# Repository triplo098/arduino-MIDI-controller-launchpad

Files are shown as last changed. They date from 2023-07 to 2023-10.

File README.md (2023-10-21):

# Arduino MIDI Controller Project

This project is a MIDI controller, based on an Arduino Pro Micro. It can generate and send MIDI messages based on user input from potentiometers, a keypad, and various configuration parameters. In other words it is DIY launchpad! 

## Video presentation
I'm using here [BandLab](https://www.bandlab.com/feed/trending)  - easy-to-use platform for creating music.

<p align="center">
<a href="http://www.youtube.com/watch?feature=player_embedded&v=7bkNr0ojT5M
" target="_blank">IMAGE ALT TEXT HERE</a>
</p>

## Libraries Used

The following libraries are used in this project:
- [MIDIUSB](https://github.com/arduino-libraries/MIDIUSB/): This library provides MIDI functionality over USB.
- [Keypad](https://github.com/Chris--A/Keypad): This library facilitates interfacing with a keypad matrix.
- [Mux](https://github.com/stechio/arduino-ad-mux-lib): This library supports multiplexing analog inputs.
- [FastLED](https://github.com/FastLED/FastLED): This library allows control of addressable LEDs.

## Functionality

The Arduino Pro Micro MIDI controller supports the following features:

- Modes of Operation:
  - The controller supports multiple modes, such as SETUP_MODE, NORMAL_MODE, and AUTO_MODE.
  - Modes can be changed using a specific keypad sequence - hold down-left + down-rigth keys for 2 seconds.

- MIDI Note Generation in NORMAL_MODE:
  - Potentiometers are used to generate MIDI control change messages.
  - Keypad buttons trigger MIDI note on and note off events.

- Tonality, Tonic and Chord Control in SETUP_MODE:
  - The tonality and tonic note can be selected using potentiometers. The same with number of notes to play. Increasing potentiometer value equals stacking more notes on top of each other in thirds, max 4 notes which gives us 7th chords eg. c e g h -> C maj7. 
  - Different scale modes (Major, Natural Minor, Harmonic Minor, Pentatonic, Chromatic) can be chosen.

- LED Visualization:
  - LEDs are used to visualize potentiometer values and sending notes.

## Usage

1. Assemble Hardware: Wire up the potentiometers, keypad, and LEDs according to the circut schematic. Print 3D parts from launchpad_parts folder, I used black PLA for top part and lucent PETG for rest, so light from LEDs was visible. 
2. Install required libraries.
3. Connect the Arduino device using USB and upload code.
4. Have fun and be creative!

## Additional Notes
Changing code structure to OOP approach- work in progress:)

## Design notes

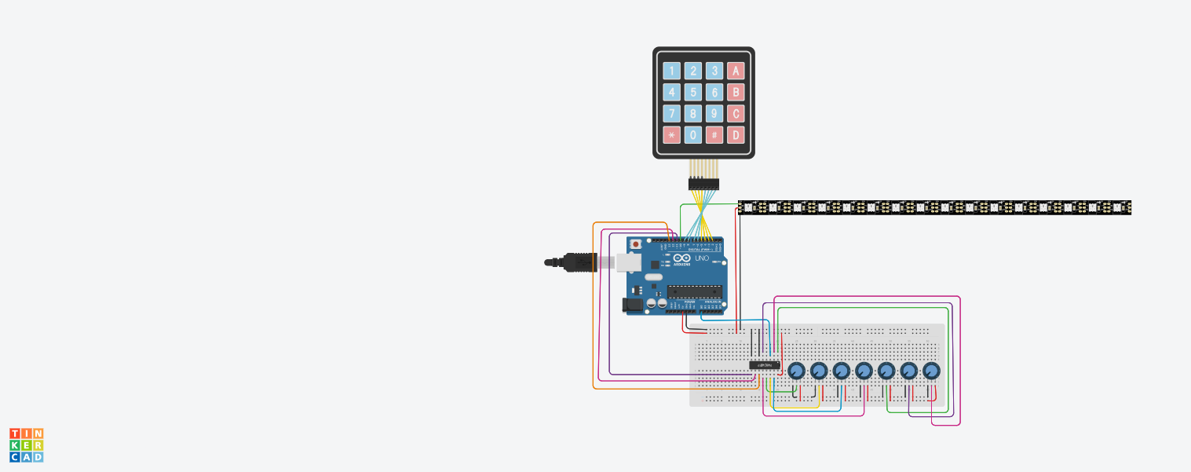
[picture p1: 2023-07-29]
launchpad_circut_schematic.png

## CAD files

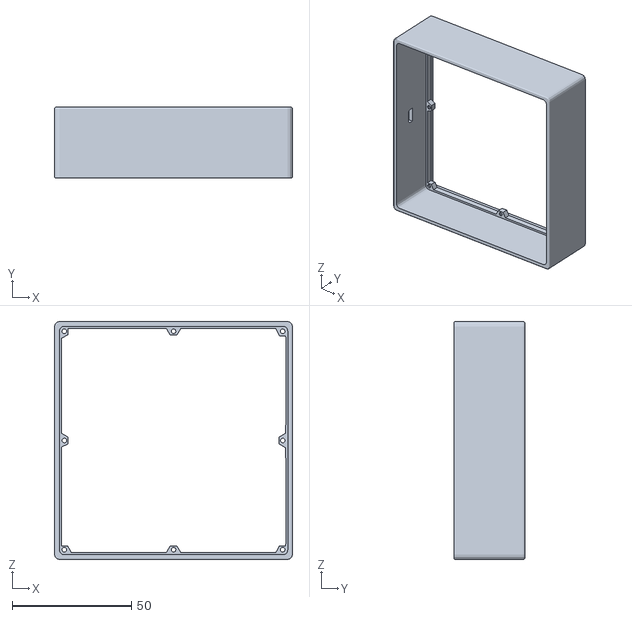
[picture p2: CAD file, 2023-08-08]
launchpad_parts/launchpad_sides.stl
100.0 x 30.0 x 100.0

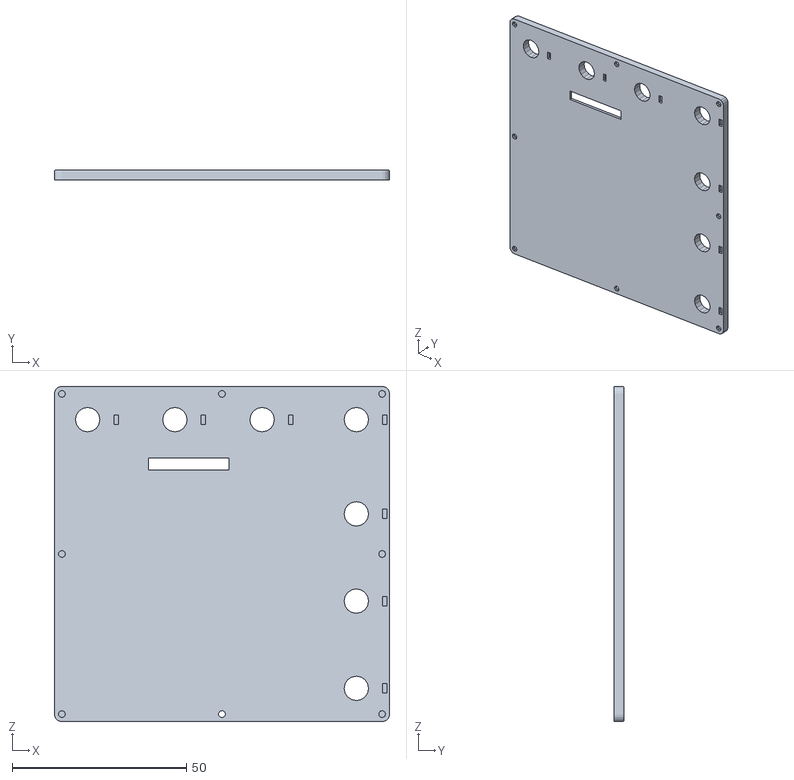
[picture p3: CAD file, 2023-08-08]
launchpad_parts/launchpad_up.stl
96.0 x 3.00 x 96.0

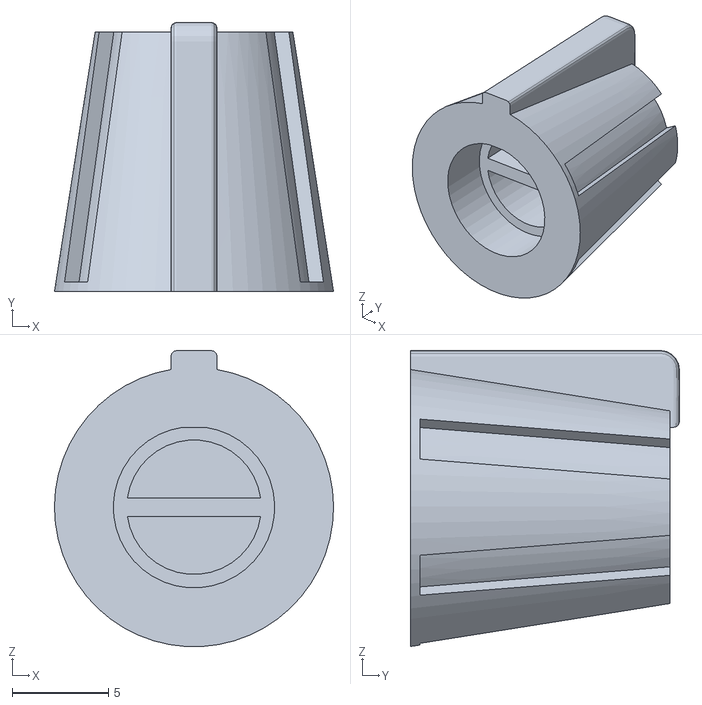
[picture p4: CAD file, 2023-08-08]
launchpad_parts/potentiometer_cap.stl
14.5 x 14.0 x 15.4

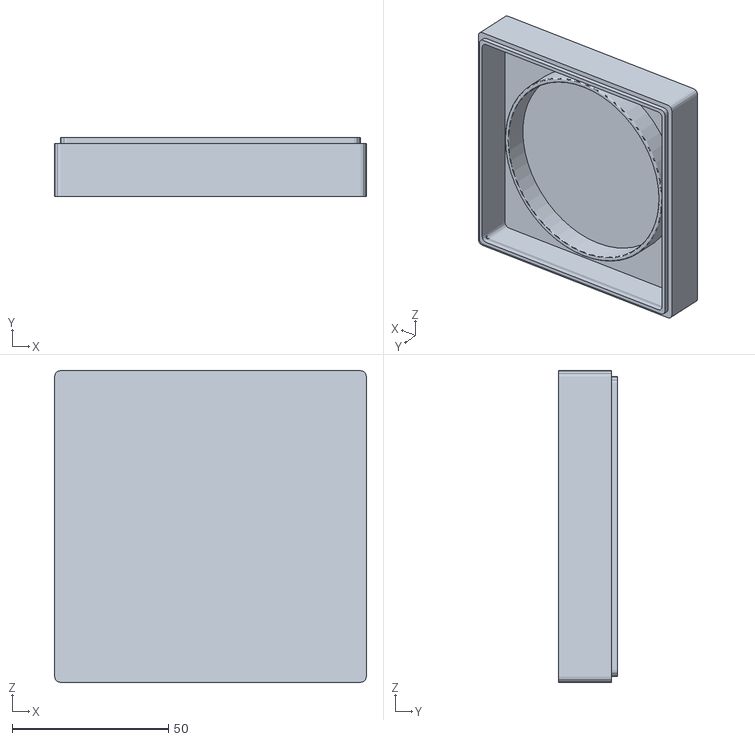
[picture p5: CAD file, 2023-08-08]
launchpad_parts/launchpad_bottom.stl
100.0 x 19.0 x 100.0

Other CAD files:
launchpad_parts/potentiometer_cap_plus_90_deg.stl

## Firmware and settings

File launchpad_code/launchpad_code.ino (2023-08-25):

#include "MIDIUSB.h"

#include <Keypad.h>

#include "Mux.h"

#include <Arduino.h>

#include <FastLED.h>


/*********************
Preparing multiplexer with potentiometers
*********************/
using namespace admux;

Mux mux(admux::Pin(A0, INPUT, PinType::Analog), Pinset(16, 15, 14));

#define NUMBER_OF_POTS 7

struct potentiometer {

  int mux_channel; 
  int control_number;
  int pre_value;
  int value;
  int channel = 0;
};

potentiometer potentiometers[NUMBER_OF_POTS];

int acceptance_rate = 16; //analong value in range betweet 0 and 1023       


/*********************
Preparing "music logic" and MIDI default parameters
*********************/
#define MAX_NOTES 12
#define MAJOR 'M'
#define MINOR_NAT 'm'
#define MINOR_HAR 'n'
#define PENTATONIC 'p'
#define CHROMATIC 'c'

byte base_velocity = 100;
byte base_channel = 0;

class scale {

  public:
  char tonality; //determine what intervals are between notes
  byte tonic;    //represents first note of scale
  byte notes[MAX_NOTES];
  byte chord_notes = 1; //number of notes stacked up while sending MIDI signal

  scale() {

    //initializing notes with error message
    for(int i = 0; i < MAX_NOTES; i++) notes[i] = 255;
    tonic = 60;
    tonality = MINOR_HAR;

    notes[0] = 0; notes[1] = 2;
    notes[2] = 4; notes[3] = 5; 
    notes[4] = 7; notes[5] = 9;
    notes[6] = 11;
  };
  
  byte count_notes() {

    byte count = 0;
    for(int i = 0; i < MAX_NOTES; i++) if(notes[i] != 255) count++;
    return count;
  }

  void set_tonic(byte tonic) {

    this -> tonic = tonic;
  }

  void set_tonality(char tonality) {

    this -> tonality = tonality;

    //error message
    for(int i = 0; i < MAX_NOTES; i++) notes[i] = 255;
    switch (tonality) {
    case 'n':
      notes[0] = 0; notes[1] = 2;
      notes[2] = 3; notes[3] = 5;
      notes[4] = 7; notes[5] = 8;
      notes[6] = 10;
      break;
    case 'm':
      notes[0] = 0; notes[1] = 2; 
      notes[2] = 3; notes[3] = 5;
      notes[4] = 7; notes[5] = 8;
      notes[6] = 11;
      break;
    case 'M':
      notes[0] = 0; notes[1] = 2;
      notes[2] = 4; notes[3] = 5; 
      notes[4] = 7; notes[5] = 9;
      notes[6] = 11;
      break;
    case 'p':
      notes[0] = 0; notes[1] = 2;
      notes[2] = 4; notes[3] = 7;
      notes[4] = 9;
      break;
    case 'c': default:
      for(int i = 0; i < MAX_NOTES; i++) notes[i] = i;      
      break;
    }    
  }
};

scale scale;


/*********************
Preparing LEDs
*********************/
#define LED_PIN 10
#define NUM_LEDS 15

int updates_per_second = 50;

CRGB leds[NUM_LEDS];

CRGBPalette16 leds_palette;
TBlendType leds_blend;

unsigned long leds_timer = 0;


/*********************
Preparing Keypad
*********************/
const byte ROWS = 4;
const byte COLS = 4;

char keys[ROWS][COLS];

byte rowPins[ROWS] = {5, 4, 3, 2};
byte colPins[COLS] = {9, 8, 7, 6}; 

Keypad kpd = Keypad( makeKeymap(keys), rowPins, colPins, ROWS, COLS );

unsigned long keys_hold_time = 0;


/*********************
Default send-MIDI functions from MIDIUSB/examples/MIDIUSB_write/MIDIUSB_write.ino
*********************/
void noteOn(byte channel, byte pitch, byte velocity) {
  midiEventPacket_t noteOn = {0x09, 0x90 | channel, pitch, velocity};
  MidiUSB.sendMIDI(noteOn);
}

void noteOff(byte channel, byte pitch, byte velocity) {
  midiEventPacket_t noteOff = {0x08, 0x80 | channel, pitch, velocity};
  MidiUSB.sendMIDI(noteOff);
}

void controlChange(byte channel, byte control, byte value) {
  midiEventPacket_t event = {0x0B, 0xB0 | channel, control, value};
  MidiUSB.sendMIDI(event);
}


#define SETUP_MODE 0
#define NORMAL_MODE 1
#define AUTO_MODE 2 //TO DO - not implemented yet

byte mode;
byte change_mode_count = 0;

void setup() {
  FastLED.addLeds<WS2812, LED_PIN, GRB>(leds, NUM_LEDS); 
  FastLED.setBrightness(100);

  leds_palette = RainbowStripeColors_p;
  leds_blend = LINEARBLEND;

  start_leds();

  for(int i = 0; i < NUMBER_OF_POTS; i++) potentiometers[i].mux_channel = i;
  
  potentiometers[0].control_number = 1;   //modulation
  potentiometers[1].control_number = 2;   //random
  potentiometers[2].control_number = 10;  //pan
  potentiometers[3].control_number = 74;  //brigthness
  potentiometers[4].control_number = 8;   //volume
  potentiometers[5].control_number = 3;  //random
  potentiometers[6].control_number = 4;  //random

  leds_timer = millis();

  mode = SETUP_MODE;
  set_color_palette(mode); 
}

void loop() {

  static byte leds_start_index = 0;

  activate_potentiometers(mode);
      
  activate_keypad(mode);
  MidiUSB.flush();

  if((millis() - leds_timer) > (1000 / updates_per_second)) {

    fill_leds_palette(leds_start_index);
    FastLED.show();
    leds_start_index++;
    leds_timer = millis();
  }
}

void activate_potentiometers(byte mode) {
  
  int mux_channel;
  int value;
  int control_number;

  for(byte i = 0; i < NUMBER_OF_POTS; i++) {
    
    control_number = potentiometers[i].control_number;

    mux_channel = potentiometers[i].mux_channel;

    value = mux.read(mux_channel);

    potentiometers[i].value = value;

    //sending change of value only if there is a known change on potentiometer
    if( potentiometers[i].value < potentiometers[i].pre_value + acceptance_rate
    && potentiometers[i].value > potentiometers[i].pre_value - acceptance_rate ) continue; 
  
    //set_color_and_progress(i, ((double) potentiometers[i].value) / 1023.0 ); 

    potentiometers[i].pre_value = potentiometers[i].value;

    if( i == 3) FastLED.setBrightness(value / 4);

    if(i == 6) updates_per_second = value / 4;

    //Sending midi control change
    if(mode == NORMAL_MODE) {
      controlChange(base_channel, control_number, value / 8);
      continue;
    }

    //Setting up parameters such as tonality, tonic, octave with potentiometers    
    if( i == 1) {
      if(value < 200) scale.set_tonality(MINOR_NAT);
      else if(value < 400) scale.set_tonality(MINOR_HAR);
      else if(value < 600) scale.set_tonality(MAJOR);
      else if(value < 800) scale.set_tonality(PENTATONIC);
      else if(value >= 800) scale.set_tonality(CHROMATIC);
      notes_to_keypad();
    }
    
    if(i == 2) {
      int temp_note = value / 8;
      if(temp_note > 20 && temp_note <= 103) {
        scale.set_tonic(temp_note);
        //note_on_time(temp_note, 100);
        notes_to_keypad();
      }
    }

    if( i == 4) {
      byte chord_mode = (value / 256) + 1;
      Serial.print("Mode: "), Serial.println(chord_mode);
      switch(chord_mode) {
        case 1: case 2: case 3: case 4:
          scale.chord_notes = chord_mode;
          break;
        default:
          scale.chord_notes = 1;
          break;
      }  
    }

    if(i == 5) {
      int octave = (value / 127);
      int temp_note = (octave * 12) + (scale.tonic % 12);
      if(temp_note > 20 && temp_note <= 103 && temp_note != scale.tonic) {
        scale.set_tonic(temp_note);
        //note_on_time(temp_note, 100);
        notes_to_keypad();
      }
    }

  }
}


void activate_keypad(byte &mode) {

  bool key_active = false;

  /*********************
  Modified part of code from Keypad/examples/MultiKey/MultiKey.ino
  *********************/
  if (kpd.getKeys()) {
    
    for (int i = 0; i < LIST_MAX; i++) {
       
      if ( kpd.key[i].stateChanged ) {

        int note = 0;
        byte octave = 0;
        switch (kpd.key[i].kstate) {  

          // Report active key state : IDLE, PRESSED, HOLD, or RELEASED
          case PRESSED:

            if(kpd.key[i].kchar == keys[3][3]) change_mode_count++;
            else if(kpd.key[i].kchar == keys[3][0]) change_mode_count++;

            if(change_mode_count == 2) {
              keys_hold_time = millis();
              clean_midi();
              continue;
            } 
                
            note = (byte) kpd.key[i].kchar;
            play_notes(true, note);
        
            break;
          case HOLD:
          key_active = true;
            break;
          case RELEASED:

            if(kpd.key[i].kchar == keys[3][3] 
            || kpd.key[i].kchar == keys[3][0]) change_mode_count = 0;

            if(change_mode_count < 2) keys_hold_time = 0;
            
            note = (byte) kpd.key[i].kchar;
            
            play_notes(false, note);

            break;
          case IDLE:
            break;
        }
      }      
    }
  }

  if((millis() - keys_hold_time > 1000) && keys_hold_time != 0) {
    
    mode++;
    mode %= 2;
    keys_hold_time = 0;
    set_color_palette(mode);
    Serial.print("Mode: "), Serial.println(mode);
  }
}

void start_leds() {

  unsigned long starting_time = millis();
  byte leds_start_index = 0;
  
  do {
    
    fill_leds_palette(leds_start_index);
    FastLED.show();
    delay(10);
    // Serial.println(leds_start_index);
    leds_start_index++;
  }
  while(millis() - starting_time < 2000);
}

void fill_leds_palette(byte color_index) {
    
  byte brightness = 255;

  for( int i = 0; i < NUM_LEDS; ++i) {

    leds[i] = ColorFromPalette(leds_palette, color_index, brightness, leds_blend);
    color_index += 2;
  }
}

void set_color_palette(byte mode) {
  switch(mode) {
    case 0: default:
    leds_palette = ForestColors_p;
      break;
    case 1:
    leds_palette = CloudColors_p;
      break;
    case 2:
    leds_palette = OceanColors_p;
      break;
  };
}

void set_color_black() {
  for(int i = 0; i < NUM_LEDS; i++) leds[i] = CRGB::Black;
}

//color depends on number of potentiometer i, progress is used to turn on proper number of leds 
void set_color_and_progress(int pot_index, double progress) {
  int num_of_leds_on = (int) (NUM_LEDS * progress);

  uint8_t red = 0;
  uint8_t green = 0;
  uint8_t blue = 0;

  //for(int i = 0; i < NUM_LEDS; i++) leds_layer[i] = leds[i];

  switch(pot_index) {
    case 0: 
      //pink
      red = 183; green = 28; blue = 28;
      break;
    case 1: 
      //light violet
      red = 69; green = 39; blue = 160;
      break;
    case 2: 
      //light cyan
      red = 67; green = 160; blue = 71;
      break;
    case 3: 
      //orange
      red = 245; green = 127; blue = 23;
      break;
    case 4: 
      //red brown
      red = 191; green = 54; blue = 12;
      break;
    // case 5: 
    //   //dark grey
    //   red = 93; green = 64; blue = 55;
    //   break;
    case 6: 
      //green
      red = 20; green = 230; blue = 20;
      break;
    default:
      red = 150; green = 64; blue = 210;
    break;
  }

  set_color_black();

  for(int i = 0; i < num_of_leds_on; i++) {
    leds[i].setRGB(red, green, blue);
  } 
}

void notes_to_keypad() {

  //Turning all of the notes from previou keypad off
  for(int i = 0 ; i < ROWS; i++) {
    for(int j = 0 ; j < COLS; j++) {
      noteOff(base_channel, (int)keys[i][j], base_velocity);
    } 
  }
  
  Serial.print("Tonic: "), Serial.println(scale.tonic);
  Serial.print("Tonality: "), Serial.println(scale.tonality);

  int note_index = 0;
  int octave = 0;  
  for(int k = 0; k < ROWS; k++) {
    for(int n = 0; n < COLS; n++) {
      int acc_note = scale.tonic;

      acc_note += scale.notes[note_index] + (12*octave);

      keys[k][n] = acc_note;

      Serial.print((int)keys[k][n]), 
      Serial.print("  "); 
      
      note_index++;
      if(note_index == scale.count_notes()) octave++;
      note_index %= scale.count_notes();
    }
    Serial.println(); 
  }
  Serial.println();
}

void activate_auto_mode() {

  static unsigned long play_time = millis();
  static byte chord_index = 0;
  
  int chords_number = 4;
  int chord_time = 1000; //time in ms
  
  // unsigned int keys_hold_time = millis();
  // unsigned int end_time = millis() + chord_time;

  //TO DO | PROPABLY BETTER IS TO USE POINTERS
  int chords[chords_number][scale.chord_notes];
  
  for(int i = 0; i < chords_number; i++) {

    //Controling likelihood of notes 
    byte graviti_notes[] = {0, 0, 0, 2, 3, 3, 4, 4, 5, 1, 1, 2, 2, 6};

    byte note_index = graviti_notes[wheel_selection_index(sizeof(graviti_notes))]; 
    byte note = scale.tonic + scale.notes[note_index];
    
    // play_notes(true, note);

    // delay(chord_time);

    // play_notes(false, note);

    //int prime = notes[sizeof(a_min_har.notes)];
    // Serial.print("chord prime: "), Serial.println(prime);
    // Serial.print("tonic note: "), Serial.println(acc_scale.tonic);

  }

  // Serial.println("Chords: ");
  // for(int i = 0; i < chords_number; i++) {
  //   for(int j = 0; j < chord_notes; j ++) {
  //     Serial.print(chords[i][j]), Serial.print(" ");
  //   }
  //   Serial.println();
  // }
}

void clean_midi() {

  //Turning all of the notes off
    for(int i = 0 ; i < 256; i++) noteOff(base_channel, i, base_velocity);
}

//Not used yet. It's should be useful while generating chords
int wheel_selection_index(int size) {
                          
  int sum = 0; 
  for(int i = 0; i < size; i++) sum += (size - i); 
  int random_number = (rand() % sum) + 1; 

  int cumulative_sum = 0;

  for (int i = 0; i < size; i++) {
        
      cumulative_sum += (size - i); 

      if(random_number <= cumulative_sum) return i;
  }
}

void play_notes(bool on, byte prime_note) {

  if(on == true ) leds_palette = LavaColors_p;
  else set_color_palette(mode);

  int chords[scale.chord_notes];

  byte octave = 0;
  byte index = 0;

  for(int i = 0; i < 3; i++){
    for(int j = 0; j < scale.count_notes(); j++) {
      if(prime_note == scale.tonic + scale.notes[j] + (i * 12)) {
        octave = i;
        index = j;
        Serial.print("Note found: "), Serial.println(prime_note);
        Serial.print("Octave and index: "), Serial.print(octave), Serial.print(" "), Serial.println(index);
      }
    }
  } 

  for(int i = 0; i < scale.chord_notes; i++) {
    if(index + i * 2 >= scale.count_notes()) octave = 1;
    else if(index + i * 2 >= 2*scale.count_notes()) octave = 2;
    chords[i] = scale.tonic + scale.notes[(index + i * 2) % scale.count_notes()] + (12 * octave);
  }

  Serial.print("chord state: "), Serial.println(on);
  Serial.print("chord: ");

  for(int i = 0; i < scale.chord_notes; i++) {
    Serial.print(chords[i]), Serial.print(" ");    
  }

  for(int note : chords) {
    if(on == true) {
      //Serial.print(note), Serial.print(" ");            
      noteOn(base_channel, note, base_velocity);
    } else {
      //Serial.print(note), Serial.print(" ");            
      noteOff(base_channel, note, base_velocity);
    }
  }
  Serial.println();
}

//Not used yet. It's for playing chodrs without using delay
void note_on_time(byte note, int timer) {

  static int time = timer;
  static unsigned long note_time = millis();
  static bool note_on = false;

  if(note_on == false) {
    noteOn(base_channel, note, base_velocity);
    note_on = true;
  } 
  else if((millis() - note_time) >= time) {
    noteOff(base_channel, note, base_velocity);
    note_on = false;
    note_time = millis();
  }
}

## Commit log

2023-07-20 Created source code for an arduino with keypad, potentiometers and basic led functionality
2023-07-27 Added multiplexer to be able to read from more potentiometers | New led functions
2023-07-29 Added circut schematic
2023-07-31 Created function for octave selection | New LEDs functions
2023-08-08 Added lanchpad 3d parts
    [lanchpad_bottom.stl, lanchpad_sides.stl, lanchpad_up.stl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]
2023-08-16 Rename all files
    [launchpad_bottom.stl, launchpad_sides.stl, launchpad_up.stl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]
2023-08-17 Add possibility of switching modes
2023-08-19 Change LEDs starting anmation | Update README
2023-08-20 Use FastLED palettes for leds
